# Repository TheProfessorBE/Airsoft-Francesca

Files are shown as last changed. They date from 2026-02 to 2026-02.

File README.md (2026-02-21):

# Hardpoint: Franceska

Airsoft hardpoint gamemode controller.
Two teams — Red and Blue — compete to hold a single capture point. Time spent holding the point is tracked and displayed in real time.

---

## Build

| Front | Internals (front) | Internals (rear) |
|---|---|---|
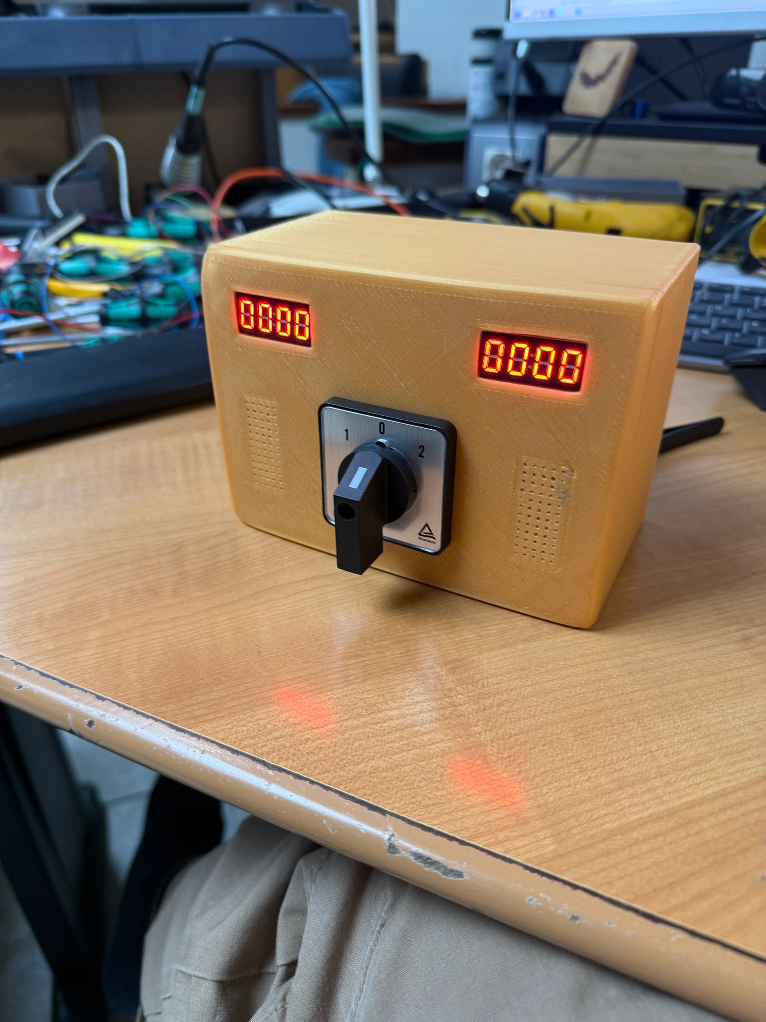
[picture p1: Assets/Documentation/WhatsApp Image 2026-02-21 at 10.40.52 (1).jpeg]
Front of unit
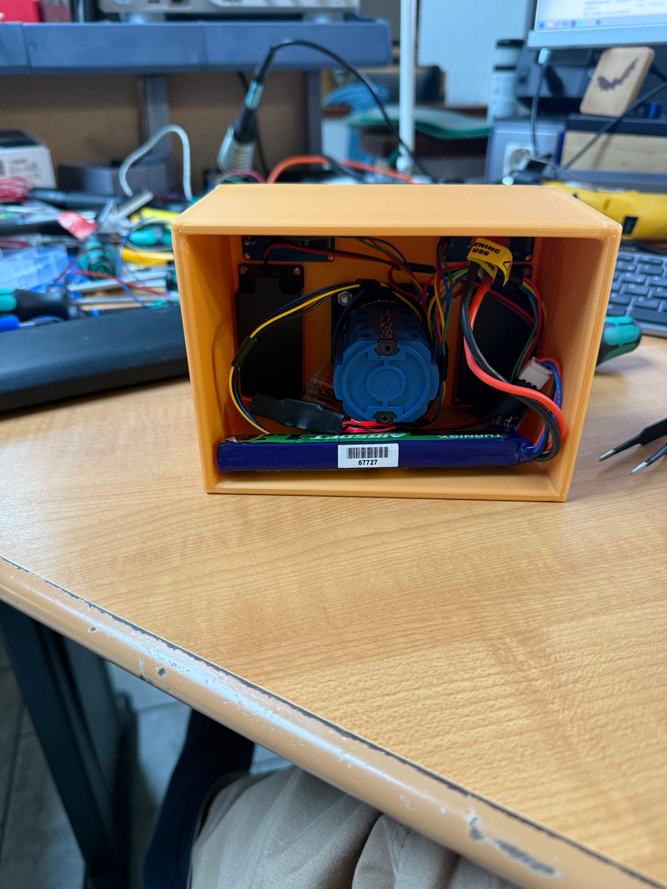
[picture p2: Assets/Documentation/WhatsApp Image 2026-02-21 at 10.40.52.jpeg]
Internals front
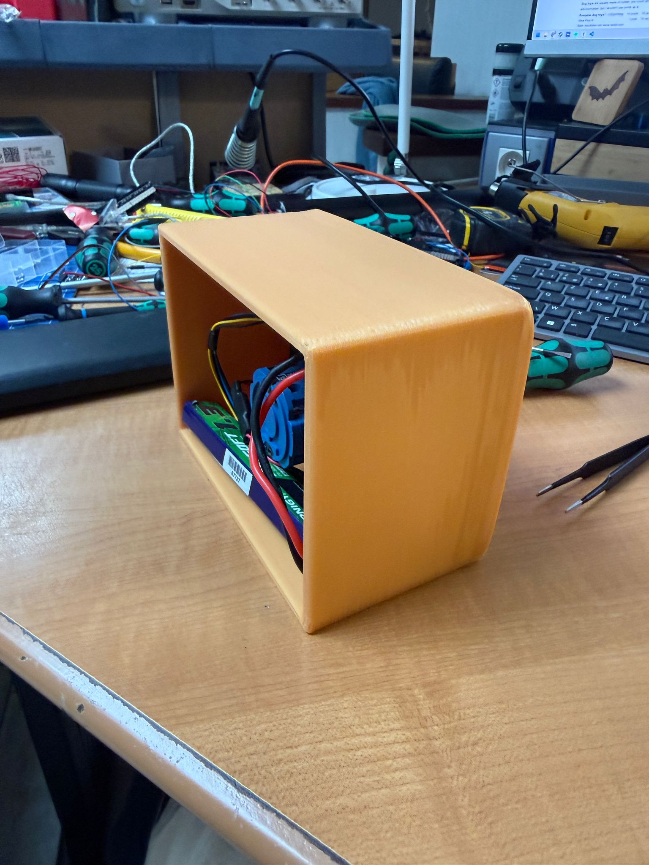
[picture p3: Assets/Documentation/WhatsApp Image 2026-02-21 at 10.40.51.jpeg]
Internals rear
|  |  |  |

3D printed enclosure housing the XIAO RP2040, two TM1637 7-segment displays, the three-way rotary switch, DFPlayer Mini, and a LiPo battery.

**Demo video:**

Demo video (https://youtube.com/shorts/hFwzT3tkaEE)

---

## Hardware

| Component | Details |
|---|---|
| Microcontroller | Seeed XIAO RP2040 |
| Switch | On-Off-On three-way switch |
| Displays | 2× TM1637 4-digit 7-segment |
| Audio | DFPlayer Mini + SD card + speaker (4–8 Ω) |

### Wiring

**Switch**
```
COM  →  GND
A    →  D2   (Red team)
B    →  D3   (Blue team)
```

**Red display (TM1637)**
```
DIO  →  D4
CLK  →  D5
VCC  →  3.3V
GND  →  GND
```

**Blue display (TM1637)**
```
DIO  →  D6
CLK  →  D7
VCC  →  3.3V
GND  →  GND
```

**DFPlayer Mini**
```
VCC  →  VBUS (5V from USB)
GND  →  GND
TX   →  D10  (Arduino RX, direct)
RX   →  D8   (Arduino TX, via 1kΩ resistor)
BUSY →  D9   (LOW = playing, HIGH = idle)
SPK1/SPK2 → speaker (4–8 Ω)
```

---

## How it works

- Switch to **Red** → Red team's timer counts up (seconds), shown on Red display
- Switch to **Blue** → Blue team's timer counts up, shown on Blue display
- Switch in **middle (neutral)** → both timers pause; point is contested

Scores are sent over serial every second in the format:
```
RED: 42s  |  BLUE: 17s  |  Holding: RED
```

The Python GUI reads this and displays it on screen.

### Voice announcements

Audio clips are queued and played in order. Each clip waits for the previous one to finish before starting.

| File | Trigger |
|---|---|
| `0001.mp3` | Red score overtakes Blue — *"Red in the lead"* |
| `0002.mp3` | Blue score overtakes Red — *"Blue in the lead"* |
| `0003.mp3` | Switch flips to Red — *"Red has the hardpoint"* |
| `0004.mp3` | Switch flips to Blue — *"Blue has the hardpoint"* |

Place the files in a folder named `mp3` on the SD card root:
```
SD card
└── mp3/
    ├── 0001.mp3
    ├── 0002.mp3
    ├── 0003.mp3
    └── 0004.mp3
```

---

## Reset sequence

To reset both scores to zero without power-cycling, flip the switch through this sequence — **each step must complete within 3 seconds**:

```
RED → (neutral) → BLUE → (neutral) → RED → (neutral)
```

The final neutral is the confirmation trigger. The Arduino zeroes both counters, clears the audio queue, updates the displays, and notifies the GUI.

> The switch physically passes through neutral between positions, so the sequence is: flip to Red, flip back, flip to Blue, flip back, flip to Red, flip back.

---

## Arduino sketch

Located in [`FranceskaArduino/FranceskaArduino/FranceskaArduino.ino`](FranceskaArduino/FranceskaArduino/FranceskaArduino.ino).

**Required libraries** — install via Arduino IDE Library Manager:

| Library | Author |
|---|---|
| `TM1637` | Avishay Orpaz |
| `DFRobotDFPlayerMini` | DFRobot |
| `SerialPIO` | Built into the arduino-pico framework |

**Timing constants** (top of sketch):

| Constant | Default | Description |
|---|---|---|
| `TICK_MS` | 1000 ms | Score increment interval |
| `DEBOUNCE_MS` | 30 ms | Switch debounce window |
| `RESET_STEP_MS` | 3000 ms | Max time between reset sequence steps |

---

## Python GUI

Located in [`FranceskaGUI/franceska_gui.py`](FranceskaGUI/franceska_gui.py).

**Install dependencies:**
```bash
pip install -r FranceskaGUI/requirements.txt
```

**Run:**
```bash
python FranceskaGUI/franceska_gui.py          # auto-detects Arduino
python FranceskaGUI/franceska_gui.py COM3     # specify port manually
```

The GUI auto-detects the Arduino by looking for CH340/CP210x/Arduino in the port description. The COM port can also be changed at runtime via **Serial → Select Port** in the menu bar.

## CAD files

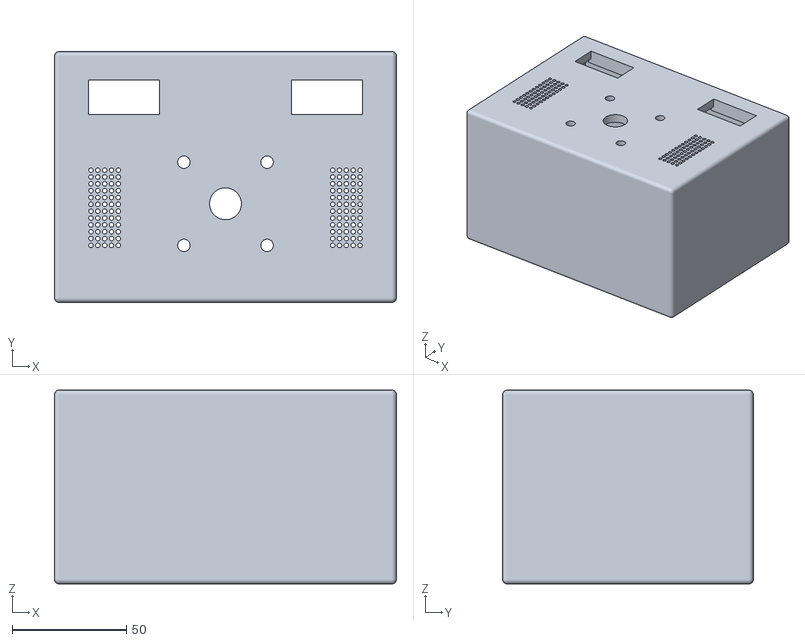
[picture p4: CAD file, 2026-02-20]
Model/case_1.stl
150.0 x 110.0 x 85.0

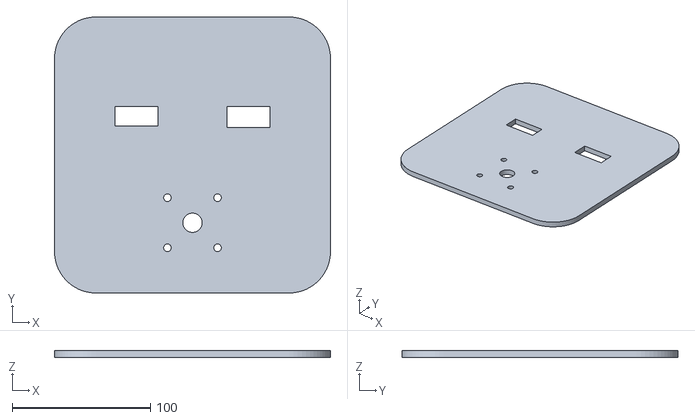
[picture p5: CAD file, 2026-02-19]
Model/basicmodel.stl
200.0 x 200.0 x 5.00

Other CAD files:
Model/OldVersions/case_1.0004.ipt
Model/basicmodel.ipt
Model/case_1.ipt

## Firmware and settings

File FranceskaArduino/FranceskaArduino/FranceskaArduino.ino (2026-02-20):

// Hardpoint Airsoft Gamemode
//
// ── Switch ───────────────────────────────────────────────────────────────────
//   COM → GND
//   A   → D2  (Red team)
//   B   → D3  (Blue team)
//
// ── TM1637 displays ──────────────────────────────────────────────────────────
//   Red  display: DIO=D4, CLK=D5
//   Blue display: DIO=D6, CLK=D7
//
// ── DFPlayer Mini ────────────────────────────────────────────────────────────
//   VCC  → VBUS (5V)
//   GND  → GND
//   TX   → D10  (Arduino RX, direct)
//   RX   → D8   (Arduino TX, via 1kΩ resistor)
//   BUSY → D9   (LOW = playing, HIGH = idle)
//   SPK1/SPK2 → speaker (4–8 Ω)
//
// ── SD card track list (place in /mp3/ folder) ───────────────────────────────
//   0001.mp3 → "Red in the lead"
//   0002.mp3 → "Blue in the lead"
//   0003.mp3 → "Red has the hardpoint"
//   0004.mp3 → "Blue has the hardpoint"
//
// ── Reset sequence ───────────────────────────────────────────────────────────
//   RED → (neutral) → BLUE → (neutral) → RED → (neutral = confirm)
//   Each step must complete within RESET_STEP_MS.

#include <TM1637Display.h>
#include <SerialPIO.h>
#include <DFRobotDFPlayerMini.h>

// ── Pins ─────────────────────────────────────────────────────────────────────
const int PIN_SW_A    = D2;
const int PIN_SW_B    = D3;
const int PIN_DF_BUSY = D9;

// TM1637Display(CLK, DIO)
TM1637Display redDisplay(D5, D4);
TM1637Display blueDisplay(D7, D6);

// DFPlayer serial: SerialPIO(TX, RX)
SerialPIO          dfSerial(D8, D10);
DFRobotDFPlayerMini dfPlayer;

// ── Audio tracks ─────────────────────────────────────────────────────────────
const uint8_t TRACK_RED_LEAD   = 1;
const uint8_t TRACK_BLUE_LEAD  = 2;
const uint8_t TRACK_RED_HOLDS  = 3;
const uint8_t TRACK_BLUE_HOLDS = 4;

// Circular queue — announcements wait until the current clip finishes
const uint8_t QUEUE_SIZE = 8;
uint8_t audioQueue[QUEUE_SIZE];
uint8_t queueHead = 0;
uint8_t queueTail = 0;

// ── Timing constants ─────────────────────────────────────────────────────────
const unsigned long TICK_MS       = 1000;
const unsigned long DEBOUNCE_MS   = 30;
const unsigned long RESET_STEP_MS = 3000;

// ── Switch positions ──────────────────────────────────────────────────────────
enum SwitchPosition : uint8_t { SW_RED, SW_NEUTRAL, SW_BLUE };

// ── Lead state ────────────────────────────────────────────────────────────────
enum LeadState : uint8_t { LEAD_TIED, LEAD_RED, LEAD_BLUE };

// ── Scores & state ────────────────────────────────────────────────────────────
unsigned long redScore  = 0;
unsigned long blueScore = 0;
LeadState     lastLead  = LEAD_TIED;

// ── Debounce state ────────────────────────────────────────────────────────────
SwitchPosition rawPos        = SW_NEUTRAL;
SwitchPosition debouncedPos  = SW_NEUTRAL;
unsigned long  debounceTimer = 0;

// ── Game state ────────────────────────────────────────────────────────────────
unsigned long lastTick = 0;

// ── Reset sequence state ──────────────────────────────────────────────────────
uint8_t       resetStep  = 0;
unsigned long resetTimer = 0;

// ── Audio helpers ─────────────────────────────────────────────────────────────

void queueTrack(uint8_t track) {
  uint8_t next = (queueTail + 1) % QUEUE_SIZE;
  if (next != queueHead) {          // drop silently if queue is full
    audioQueue[queueTail] = track;
    queueTail = next;
  }
}

void clearAudioQueue() {
  queueHead = queueTail = 0;
  dfPlayer.stop();
}

// Called every loop(). Starts the next queued track only when the
// DFPlayer BUSY pin goes HIGH (current clip has finished).
void updateAudio() {
  if (digitalRead(PIN_DF_BUSY) == LOW) return;  // still playing
  if (queueHead == queueTail)          return;  // nothing queued
  dfPlayer.play(audioQueue[queueHead]);
  queueHead = (queueHead + 1) % QUEUE_SIZE;
}

// ── Switch & debounce ─────────────────────────────────────────────────────────

SwitchPosition readRaw() {
  bool a = digitalRead(PIN_SW_A) == LOW;
  bool b = digitalRead(PIN_SW_B) == LOW;
  if (a && !b) return SW_RED;
  if (!a && b) return SW_BLUE;
  return SW_NEUTRAL;
}

bool updateDebounce() {
  SwitchPosition raw = readRaw();
  unsigned long  now = millis();
  if (raw != rawPos) {
    rawPos        = raw;
    debounceTimer = now;
  }
  if ((now - debounceTimer >= DEBOUNCE_MS) && (rawPos != debouncedPos)) {
    debouncedPos = rawPos;
    return true;
  }
  return false;
}

// ── Display & serial output ───────────────────────────────────────────────────

void updateDisplays() {
  redDisplay.showNumberDec(min(redScore,  9999UL), true);
  blueDisplay.showNumberDec(min(blueScore, 9999UL), true);
}

void printStatus() {
  const char* holder;
  switch (debouncedPos) {
    case SW_RED:  holder = "RED";     break;
    case SW_BLUE: holder = "BLUE";    break;
    default:      holder = "NEUTRAL"; break;
  }
  Serial.print("RED: ");        Serial.print(redScore);
  Serial.print("s  |  BLUE: "); Serial.print(blueScore);
  Serial.print("s  |  Holding: "); Serial.println(holder);
}

// ── Reset ─────────────────────────────────────────────────────────────────────

void doReset() {
  redScore  = 0;
  blueScore = 0;
  lastLead  = LEAD_TIED;
  clearAudioQueue();
  updateDisplays();
  Serial.println(">> SCORES RESET");
  printStatus();
}

// ── Reset sequence detector ───────────────────────────────────────────────────

void checkResetSequence(SwitchPosition pos) {
  unsigned long now = millis();

  if (resetStep > 0 && (now - resetTimer) > RESET_STEP_MS) {
    resetStep = 0;
  }

  if (pos == SW_NEUTRAL) {
    if (resetStep == 3) { doReset(); resetStep = 0; }
    return;
  }

  switch (resetStep) {
    case 0: if (pos == SW_RED)  { resetStep = 1; resetTimer = now; } break;
    case 1: if (pos == SW_BLUE) { resetStep = 2; resetTimer = now; }
            else                { resetStep = 0; } break;
    case 2: if (pos == SW_RED)  { resetStep = 3; resetTimer = now; }
            else                { resetStep = 0; } break;
    case 3: resetStep = 0; break;
  }
}

// ── Setup ─────────────────────────────────────────────────────────────────────

void setup() {
  Serial.begin(9600);
  pinMode(PIN_SW_A,    INPUT_PULLUP);
  pinMode(PIN_SW_B,    INPUT_PULLUP);
  pinMode(PIN_DF_BUSY, INPUT);

  redDisplay.setBrightness(0x0f);
  blueDisplay.setBrightness(0x0f);
  updateDisplays();

  dfSerial.begin(9600);
  delay(200);                          // let DFPlayer boot
  if (dfPlayer.begin(dfSerial, false)) // false = no ACK, faster response
    dfPlayer.volume(5);               // 0–30
  else
    Serial.println(">> DFPlayer init failed");

  lastTick = millis();
  Serial.println("=== HARDPOINT STARTED ===");
  printStatus();
}

// ── Loop ──────────────────────────────────────────────────────────────────────

void loop() {
  unsigned long now        = millis();
  bool          posChanged = updateDebounce();

  updateAudio();   // pump the queue — fires next clip only when BUSY goes HIGH

  if (posChanged) {
    checkResetSequence(debouncedPos);

    switch (debouncedPos) {
      case SW_RED:
        Serial.println(">> RED holds");
        queueTrack(TRACK_RED_HOLDS);
        break;
      case SW_NEUTRAL:
        Serial.println(">> Contested");
        break;
      case SW_BLUE:
        Serial.println(">> BLUE holds");
        queueTrack(TRACK_BLUE_HOLDS);
        break;
    }
  }

  // Score tick every second
  if (now - lastTick >= TICK_MS) {
    lastTick += TICK_MS;
    if (debouncedPos == SW_RED)  redScore++;
    if (debouncedPos == SW_BLUE) blueScore++;
    updateDisplays();
    printStatus();

    // Queue a lead announcement only when the lead changes hands
    LeadState currentLead = (redScore  > blueScore) ? LEAD_RED  :
                            (blueScore > redScore)  ? LEAD_BLUE : LEAD_TIED;
    if (currentLead != lastLead && currentLead != LEAD_TIED) {
      queueTrack(currentLead == LEAD_RED ? TRACK_RED_LEAD : TRACK_BLUE_LEAD);
    }
    lastLead = currentLead;
  }
}

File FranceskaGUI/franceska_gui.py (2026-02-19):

"""
HARDPOINT: FRANCESKA
Hardpoint gamemode controller

Reads Arduino serial output and displays live scores for Red vs Blue.

Usage:
    pip install -r requirements.txt
    python franceska_gui.py [COM_PORT]     # e.g. python franceska_gui.py COM3

If no port is given the script auto-detects the first Arduino it finds.
"""

import sys
import re
import threading
import urllib.request
import io
import tkinter as tk
from tkinter import font as tkfont

try:
    from PIL import Image, ImageTk
    HAS_PIL = True
except ImportError:
    HAS_PIL = False

try:
    import serial
    import serial.tools.list_ports
    HAS_SERIAL = True
except ImportError:
    HAS_SERIAL = False

# ── Logo ─────────────────────────────────────────────────────────────────────
LOGO_URL  = "https://pagemaker.b-cdn.net/media/71928/400x50.png"
LOGO_SIZE = (280, 35)   # display size in the header

# ── Serial ────────────────────────────────────────────────────────────────────
BAUD_RATE = 9600

# ── Palette ───────────────────────────────────────────────────────────────────
BG          = "#0f0f0f"
PANEL_BG    = "#1a1a1a"
DIVIDER     = "#2a2a2a"
RED_COL     = "#e63946"
BLUE_COL    = "#4895ef"
NEUTRAL_COL = "#888888"
FG          = "#f1faee"
BAR_BG      = "#0a0a0a"

# Line patterns from Arduino
RE_SCORE = re.compile(
    r"RED:\s*(\d+)s\s*\|\s*BLUE:\s*(\d+)s\s*\|\s*Holding:\s*(\w+)",
    re.IGNORECASE,
)


# ── Serial reader (background thread) ────────────────────────────────────────
class SerialReader(threading.Thread):
    def __init__(self, port, on_line):
        super().__init__(daemon=True)
        self.port    = port
        self.on_line = on_line
        self.ser     = None

    def run(self):
        if not HAS_SERIAL:
            self.on_line("__ERROR__pyserial not installed. Run: pip install pyserial")
            return
        try:
            self.ser = serial.Serial(self.port, BAUD_RATE, timeout=1)
            while True:
                raw = self.ser.readline()
                if raw:
                    line = raw.decode("utf-8", errors="ignore").strip()
                    if line:
                        self.on_line(line)
        except Exception as exc:
            self.on_line(f"__ERROR__{exc}")

    def close(self):
        if self.ser and self.ser.is_open:
            self.ser.close()


# ── Helpers ───────────────────────────────────────────────────────────────────
def fmt_time(seconds: int) -> str:
    """Format seconds as M:SS for readability once past 60 s."""
    if seconds < 60:
        return f"{seconds}s"
    return f"{seconds // 60}m {seconds % 60:02d}s"


def load_logo(url: str, size: tuple) -> "ImageTk.PhotoImage | None":
    if not HAS_PIL:
        return None
    try:
        with urllib.request.urlopen(url, timeout=4) as resp:
            data = resp.read()
        img = Image.open(io.BytesIO(data)).convert("RGBA")
        img = img.resize(size, Image.LANCZOS)
        return ImageTk.PhotoImage(img)
    except Exception:
        return None


# ── GUI ───────────────────────────────────────────────────────────────────────
class HardpointGUI:
    def __init__(self, root: tk.Tk, port: str | None = None):
        self.root       = root
        self.red_score  = 0
        self.blue_score = 0
        self.holding    = "NEUTRAL"
        self.reader: SerialReader | None = None

        root.title("HARDPOINT: FRANCESKA")
        root.configure(bg=BG)
        root.geometry("920x540")
        root.resizable(False, False)

        self._build_menu()
        self._build_ui()
        self._connect(port)

    # ── Menu bar ──────────────────────────────────────────────────────────────
    def _build_menu(self):
        menubar = tk.Menu(self.root, bg="#1a1a1a", fg=FG, tearoff=False,
                          activebackground="#2a2a2a", activeforeground=FG,
                          borderwidth=0)

        serial_menu = tk.Menu(menubar, bg="#1a1a1a", fg=FG, tearoff=False,
                              activebackground="#2a2a2a", activeforeground=FG)
        serial_menu.add_command(label="Select Port…", command=self._open_port_dialog)
        serial_menu.add_command(label="Disconnect",   command=self._disconnect)
        serial_menu.add_separator()
        serial_menu.add_command(label="Refresh Port List",
                                command=self._open_port_dialog)

        menubar.add_cascade(label="Serial", menu=serial_menu)
        self.root.config(menu=menubar)

    # ── Port selector dialog ──────────────────────────────────────────────────
    def _open_port_dialog(self):
        if not HAS_SERIAL:
            return

        ports = list(serial.tools.list_ports.comports())

        dlg = tk.Toplevel(self.root)
        dlg.title("Select COM Port")
        dlg.configure(bg=PANEL_BG)
        dlg.resizable(False, False)
        dlg.grab_set()          # modal
        dlg.transient(self.root)

        # ── Header ────────────────────────────────────────────────────────────
        tk.Label(dlg, text="Select COM Port", fg=FG, bg=PANEL_BG,
                 font=("Helvetica Neue", 14, "bold")).pack(padx=24, pady=(16, 4))
        tk.Label(dlg, text="Available serial ports:", fg=NEUTRAL_COL, bg=PANEL_BG,
                 font=("Helvetica Neue", 10)).pack(padx=24)

        tk.Frame(dlg, bg=DIVIDER, height=1).pack(fill="x", padx=16, pady=8)

        # ── Port list ─────────────────────────────────────────────────────────
        list_frame = tk.Frame(dlg, bg=PANEL_BG)
        list_frame.pack(padx=16, fill="both")

        selected_port = tk.StringVar(value="")

        if not ports:
            tk.Label(list_frame, text="No ports found.", fg=NEUTRAL_COL,
                     bg=PANEL_BG, font=("Courier New", 10)).pack(pady=8)
        else:
            for p in ports:
                desc  = p.description or p.device
                label = f"{p.device}  —  {desc}"
                rb = tk.Radiobutton(
                    list_frame, text=label,
                    variable=selected_port, value=p.device,
                    fg=FG, bg=PANEL_BG, selectcolor="#2a2a2a",
                    activebackground=PANEL_BG, activeforeground=FG,
                    font=("Courier New", 10), anchor="w",
                )
                rb.pack(fill="x", pady=2)

            # Pre-select currently connected port or best guess
            current = self.reader.port if self.reader else self._auto_detect()
            if current and any(p.device == current for p in ports):
                selected_port.set(current)
            elif ports:
                selected_port.set(ports[0].device)

        tk.Frame(dlg, bg=DIVIDER, height=1).pack(fill="x", padx=16, pady=8)

        # ── Buttons ───────────────────────────────────────────────────────────
        btn_frame = tk.Frame(dlg, bg=PANEL_BG)
        btn_frame.pack(padx=16, pady=(0, 16), fill="x")
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

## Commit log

2026-02-20 some updates
    [case_1.0002.ipt, case_1.ipt, case_1.stl]
2026-02-20 pushing audio
    [case_1.0002.ipt, case_1.0003.ipt, case_1.ipt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]
2026-02-20 update of case
    [case_1.0003.ipt, case_1.0004.ipt, case_1.ipt]
